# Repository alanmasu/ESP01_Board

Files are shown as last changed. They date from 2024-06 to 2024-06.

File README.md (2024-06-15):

# ESP01 Board
## Description
This board is inspired from the classic ESP01 Relay board. 
In the large case of Relay boards, you can find the same problems like the relay is driven LOW end when the ESP boots up, the relay is triggered since the ESP boot reaches the end of the setup function when the GPIO pin is set to LOW.

The ESP01 Board is designed to solve these problems, but also to provide a more stable and flexible solution for your projects.

The output stage of strapping pins is latched and modifyng the time constant of the RC (R12-C7 and R13-C8) you can change the time of the latching. The default latched time is about 210ms for certain, but the latces become transparent after 545ms due to the $V_{IL}$ of the Latch is $0,9V$ so the latch is completally transparent when the RC circuit reaches $0,9V$; in the range of $2V - 0,9V$ the behavior of the latch is unpredictable.

## Features
- ESP01/ESP01-S Module
- 1x Relay 5V or 3.3V (hardware configurable whit a jumper)
- 2x NMOS Output Stage, 
- 2x NMOS Latched Output Stage,
- 4x Input Stage, with 2 of them pulled up to 3.3V with a 10K resistor,
- 1x 3.3V LDO Regulator,
- 1x fuse for the 5V input,
- USB Type-C Connector for power supply (or a classic pin header).

## Note
> If you need the UART pins, you can use the I1 and I3 pins but you need to remove the 10K resistor (R2 and R3) and the NMOS (Q1 and Q2) from the board.

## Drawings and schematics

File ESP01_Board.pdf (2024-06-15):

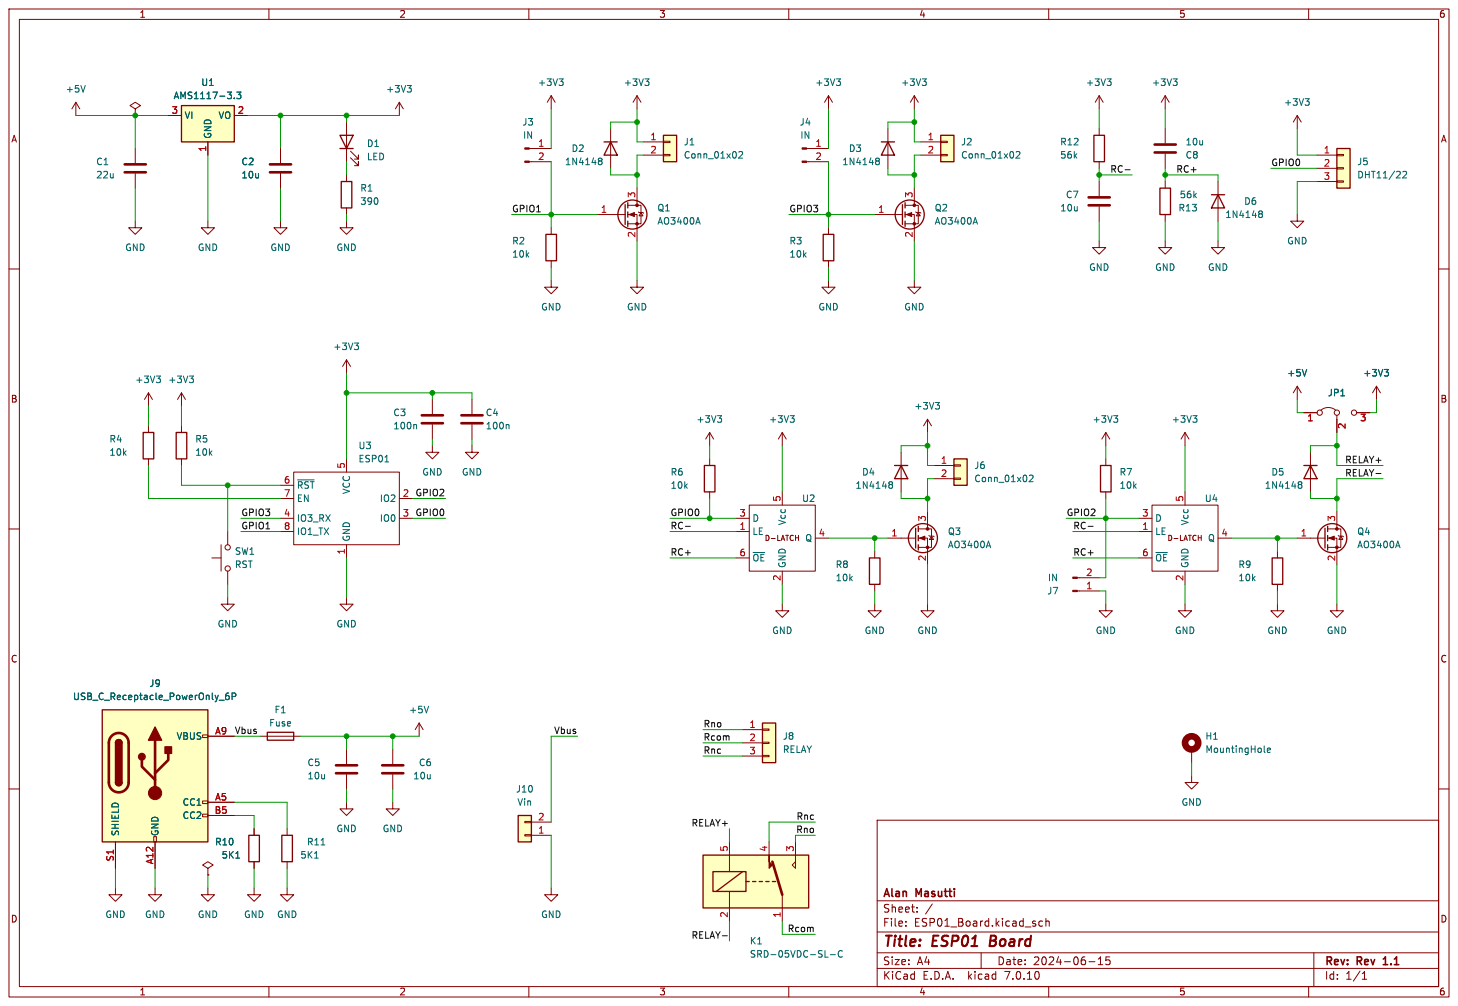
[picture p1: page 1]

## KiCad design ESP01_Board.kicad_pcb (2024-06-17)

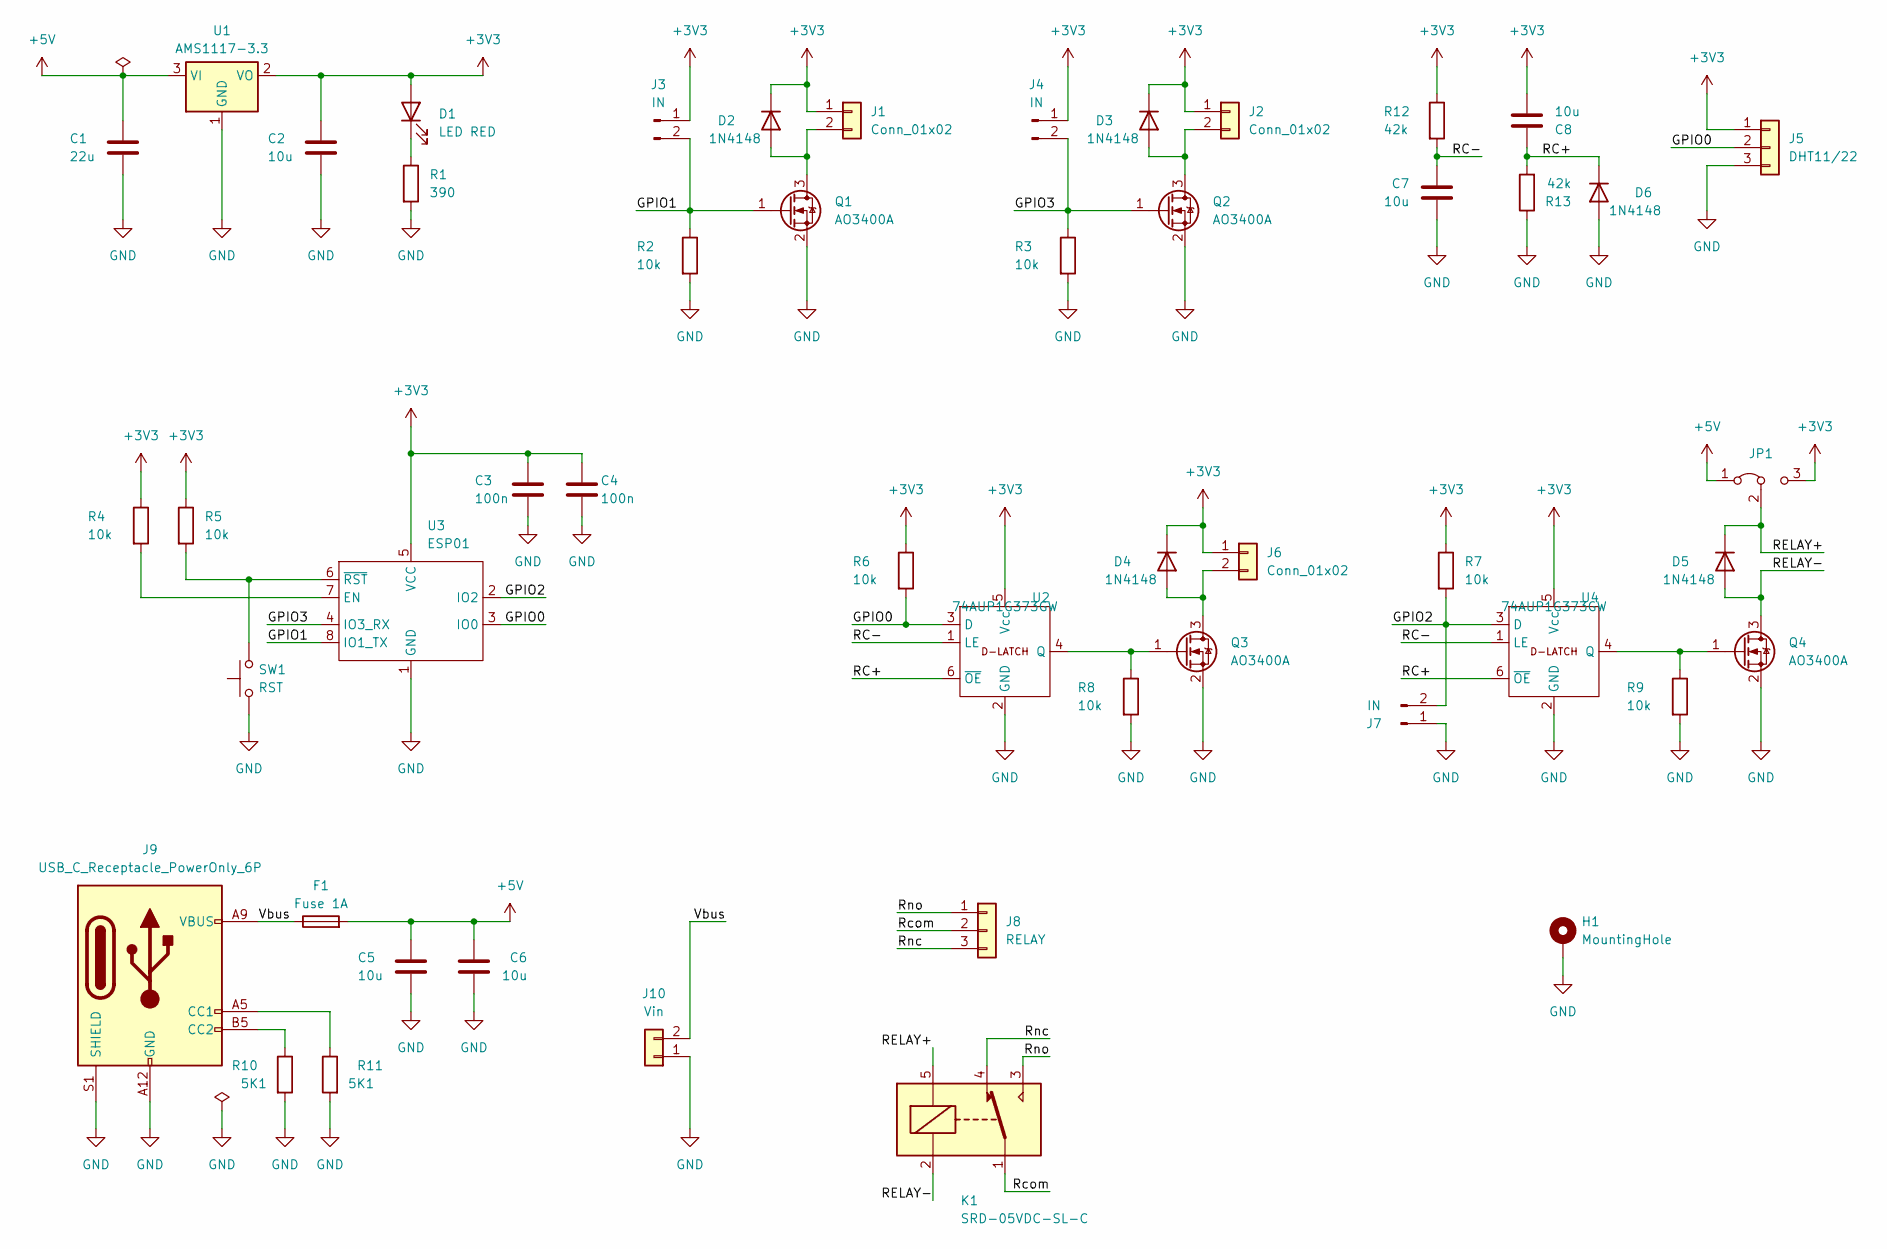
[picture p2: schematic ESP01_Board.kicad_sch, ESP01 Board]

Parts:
C1: 22u; C_0805_2012Metric; LCSC C2918507
C2, C5, C6, C7, C8: 10u; C_0805_2012Metric; LCSC C3015161
C3, C4: 100n; C_0805_2012Metric; LCSC C2991409
D1: LED RED; D_0805_2012Metric_Pad1.15x1.40mm_HandSolder; LCSC C7496834
D2, D3, D4, D5, D6: 1N4148; D_SOD-123; LCSC C7420318
F1: Fuse 1A; Fuse_1206_3216Metric_Pad1.42x1.75mm_HandSolder; LCSC C151135
H1: MountingHole; MountingHole_3.2mm_M3_ISO14580_Pad
J1, J2, J6: Conn_01x02; PinHeader_1x02_P2.54mm_Vertical
J3, J4, J7: IN; PinHeader_SMD_1x02_P2.54
J5: DHT11/22; PinHeader_1x03_P2.54mm_Vertical
J8: RELAY; PinHeader_1x03_P2.54mm_Vertical; LCSC C35449
J9: USB_C_Receptacle_PowerOnly_6P; USB_C_Receptacle_GCT_USB4125-xx-x_6P_TopMnt_Horizontal; LCSC C2927027
J10: Vin; PinHeader_1x02_P2.54mm_Vertical
JP1: Jumper_3_Bridged12; SolderJumper-3_P1.3mm_Bridged12_Pad1.0x1.5mm
K1: SRD-05VDC-SL-C; Relay_SPDT_SANYOU_SRD_Series_Form_C; LCSC C35449
Q1, Q2, Q3, Q4: AO3400A; SOT-23; LCSC C347475
R1: 390; R_0805_2012Metric; LCSC C17655
R2, R3, R4, R5, R6, R7, R8, R9: 10k; R_0805_2012Metric; LCSC C17414
R10, R11: 5K1; R_0805_2012Metric; LCSC C27834
R12, R13: 42k; R_0805_2012Metric; LCSC C4151965
SW1: RST; SW_PUSH_1P1T_6x3.5mm_H5.0_APEM_MJTP1250
U1: AMS1117-3.3; SOT-223-3_TabPin2; LCSC C5120765
U2, U4: 74AUP1G373GW; SOT-363_SC-70-6; LCSC C458800
U3: ESP01

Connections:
+3V3: C2.1, C3.1, C4.1, C8.2, D1.2 (A), D2.1 (K), D3.1 (K), D4.1 (K), J1.1, J2.1, J3.1, J4.1, J5.1, J6.1, JP1.3 (B), R4.1, R5.1, R6.1, R7.1, R12.1, U1.2 (VO), U2.5 (Vcc), U3.5 (VCC), U4.5 (Vcc)
+5V: C1.1, C5.1, C6.1, F1.2, JP1.1 (A), U1.3 (VI)
/GPIO0: J5.2, R6.2, U2.3 (D), U3.3 (IO0)
/GPIO1: J3.2, Q1.1 (G), R2.1, U3.8 (IO1_TX)
/GPIO2: J7.2, R7.2, U3.2 (IO2), U4.3 (D)
/GPIO3: J4.2, Q2.1 (G), R3.1, U3.4 (IO3_RX)
/RC+: C8.1, D6.1 (K), R13.2, U2.6 (~OE), U4.6 (~OE)
/RC-: C7.1, R12.2, U2.1 (LE), U4.1 (LE)
/RELAY+: D5.1 (K), JP1.2 (C), K1.5
/RELAY-: D5.2 (A), K1.2, Q4.3 (D)
/Rcom: J8.2, K1.1
/Rnc: J8.3, K1.4
/Rno: J8.1, K1.3
/Vbus: F1.1, J9.A9 (VBUS), J9.B9 (VBUS), J10.2
GND: C1.2, C2.2, C3.2, C4.2, C5.2, C6.2, C7.2, D6.2 (A), H1.1, J5.3, J7.1, J9.A12 (GND), J9.B12 (GND), J9.S1 (SHIELD), J10.1, Q1.2 (S), Q2.2 (S), Q3.2 (S), Q4.2 (S), R1.2, R2.2, R3.2, R8.2, R9.2, R10.2, R11.2, R13.1, SW1.1, U1.1 (GND), U2.2 (GND), U3.1 (GND), U4.2 (GND)
unnamed: D1.1 (K), R1.1
unnamed: D2.2 (A), J1.2, Q1.3 (D)
unnamed: D3.2 (A), J2.2, Q2.3 (D)
unnamed: D4.2 (A), J6.2, Q3.3 (D)
unnamed: J9.A5 (CC1), R11.1
unnamed: J9.B5 (CC2), R10.1
unnamed: Q3.1 (G), R8.1, U2.4 (Q)
unnamed: Q4.1 (G), R9.1, U4.4 (Q)
unnamed: R4.2, U3.7 (EN)
unnamed: R5.2, SW1.2, U3.6 (~RST)

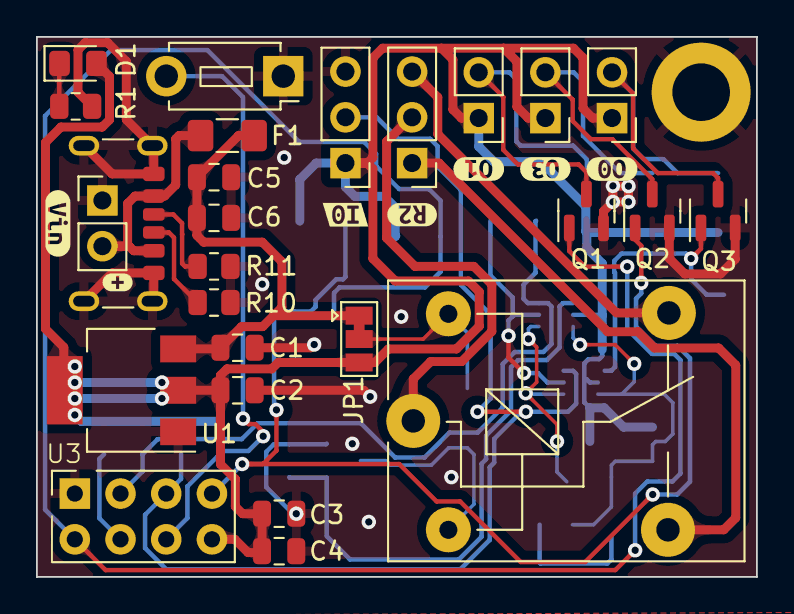
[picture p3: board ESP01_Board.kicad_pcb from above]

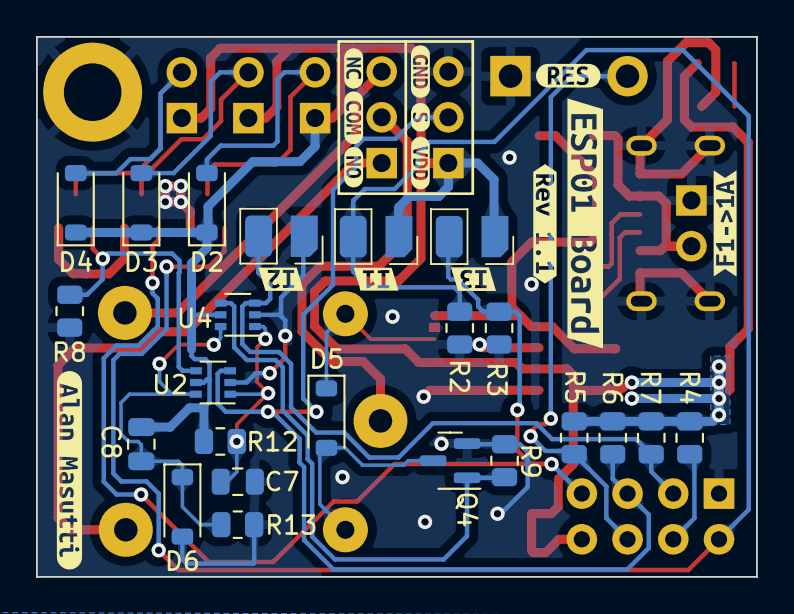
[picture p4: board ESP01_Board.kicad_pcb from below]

Board: 2 copper layers, 40.0 x 30.0 mm, 71 parts (37 on the bottom side), 25 nets.

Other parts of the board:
kibuzzard-666D62C0: G***; kibuzzard-666D62C0
kibuzzard-666D62C8: G***; kibuzzard-666D62C8
kibuzzard-666D62F4: G***; kibuzzard-666D62F4
kibuzzard-666D66A3: G***; kibuzzard-666D66A3
kibuzzard-666D627E: G***; kibuzzard-666D627E
kibuzzard-666D664B: G***; kibuzzard-666D664B
kibuzzard-666D6245: G***; kibuzzard-666D6245
kibuzzard-666D6261: G***; kibuzzard-666D6261
kibuzzard-666D6272: G***; kibuzzard-666D6272
kibuzzard-666D6286: G***; kibuzzard-666D6286
kibuzzard-666D6307: G***; kibuzzard-666D6307
kibuzzard-666D6618: G***; kibuzzard-666D6618
kibuzzard-666D6651: G***; kibuzzard-666D6651
kibuzzard-666D6656: G***; kibuzzard-666D6656
kibuzzard-666FE76E: G***; kibuzzard-666FE76E
kibuzzard-6669B1E4: G***; kibuzzard-6669B1E4
kibuzzard-6669B4DA: G***; kibuzzard-6669B4DA
kibuzzard-6669B4F4: G***; kibuzzard-6669B4F4
kibuzzard-6669B213: G***; kibuzzard-6669B213
kibuzzard-6669B231: G***; kibuzzard-6669B231
kibuzzard-6669B493: G***; kibuzzard-6669B493

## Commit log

2024-06-12 First commit
    Added the project to GIT
    [ESP01_Board.kicad_pcb, ESP01_Board.kicad_sch]
2024-06-13 Conclusa la prima versione
    - Inserite le serigrafie e controllato il circuito
    [ESP01_Board.kicad_pcb, ESP01_Board.kicad_sch]
2024-06-13 Modificato lo stadio di ingresso
    - Aggiunti i D-latch per l'utilizzo dei due GPIO di strapping
    - Corretto il Cartiglio dello schematico e compilato quello del foglio del PCB
    [ESP01_Board.kicad_pcb, ESP01_Board.kicad_sch]
2024-06-13 Aggiunti i teardrops
    [ESP01_Board.kicad_pcb]
2024-06-13 Cambiati i footprint ai due Latch
    - Probabilmente ho fatto altre modifiche grafiche alla scheda,
    - Ho fatto delle stampe dei layer quindi anche sulle impostazioni qualcosa può essere cambiato
    [ESP01_Board.kicad_pcb]
2024-06-13 Aggiunto il README [TO FINISH
2024-06-15 Completata Rev1.1
    - Sistemati Errori di sovrascritture (Vedi ad esempio i cartigli)
    - Sistemata la BOM
    - Corrette le Serigrafie
    - Controllato il design
    [ESP01_Board.kicad_pcb, ESP01_Board.kicad_sch]
2024-06-17 Aggiunti i codici LCSC + Aggiornato footprint del fuse
    - Aggiunta anche la serigrafia con il valore del fusibile,
    - Aggiornata la data sul foglio del PCB,
    - Ricreati i teardrop
    [ESP01_Board.kicad_pcb, ESP01_Board.kicad_sch]
